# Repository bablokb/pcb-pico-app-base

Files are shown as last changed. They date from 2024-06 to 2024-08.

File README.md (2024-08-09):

Generic application base PCB for the Raspberry Pi Pico(W)
=========================================================

**This is work in progress**

A generic application base PCB for the Pi Pico(W) and compatible
development boards.

Core features:

  - RTC (PCF8563)
  - integrated power-management with
    - near zero power-off current
    - time-based wake up via RTC-alarm
    - wake up via interrupt (e.g. with a button)
    - JST-PH2 LiPo connector
    - LiPo charging
    - battery fuel-gauge
  - I2C connectors (Stemma/Qt and Grove)
  - EYESPI connector
  - integrated XTSD-chip for data-storage
  - additional THT for all GPIOs
  - multiple 3V3+GND connectors

License
-------

[![CC BY-SA 4.0][cc-by-sa-shield]][cc-by-sa]

This work is licensed under a
[Creative Commons Attribution-ShareAlike 4.0 International
License][cc-by-sa].

[][cc-by-sa]

[cc-by-sa]: http://creativecommons.org/licenses/by-sa/4.0/
[cc-by-sa-image]: https://licensebuttons.net/l/by-sa/4.0/88x31.png
[cc-by-sa-shield]:
https://img.shields.io/badge/License-CC%20BY--SA%204.0-lightgrey.svg

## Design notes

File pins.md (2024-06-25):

Pins
====

Pins on Raspberry Pi Pico
-------------------------

| | Pin  | Pin  | |
|---|---|---|---|
| | GP0  | VBUS |
| | GP1  | VSYS |
| | GND  | GND  |
| I2C1-SDA (RTC) | GP2  | EN |
| I2C1-SCL (RTC) | GP3  | 3V3  |
| DONE (Flip-Flop) | GP4  | VREF |
| | GP5  | GP28 | 
| | GND  | GND  |
| | GP6  | GP27 |
| | GP7  | GP26 | Display Busy (EYESPI)
| | GP8  | RUN  | RUN
| LCD-BL (EYESPI) | GP9  | GP22 | SD-CS (SD-Card)
| | GND  | GND  |
| | GP10 | GP21 | Display Reset (EYESPI)
| MEM-CS (EYESPI) | GP11 | GP20 | Display D/C (EYESPI)
| GPIO1 (EYESPI) | GP12 | GP19 | MOSI0 (EYESPI, SD-Card)
| GPIO2 (EYESPI) | GP13 | GP18 | SCLK0 (EYESPI, SD-Card)
| | GND  | GND  |
| TS-CS (EYESPI) | GP14 | GP17 | Display CS (EYESPI)
| INT (EYESPI) | GP15 | GP16 | MISO0 (EYESPI, SD-Card)

Pins on EYESPI
--------------

| Pin | Func | Mapped to
|-----|---|---|
| 1 | GPIO2 | GP13
| 2 | GPIO1 | GP12
| 3 | BUSY | GP26
| 4 | INT | GP15
| 5 | SDA | GP2
| 6 | SCL | GP3
| 7 | TS_CS | GP14
| 8 | MEM_CS  | GP11
| 9 | SD_CS | n.c.
|  10 | DISP_CS | GP17
|  11 | RESET | GP21
|  12 | DC | GP20
|  13 | MISO | GP16
|  14 | MOSI | GP19
|  15 | SCK | GP18
|  16 | GND | GND
|  17 | BLITE | GP9
|  18 | VCC | 3V3

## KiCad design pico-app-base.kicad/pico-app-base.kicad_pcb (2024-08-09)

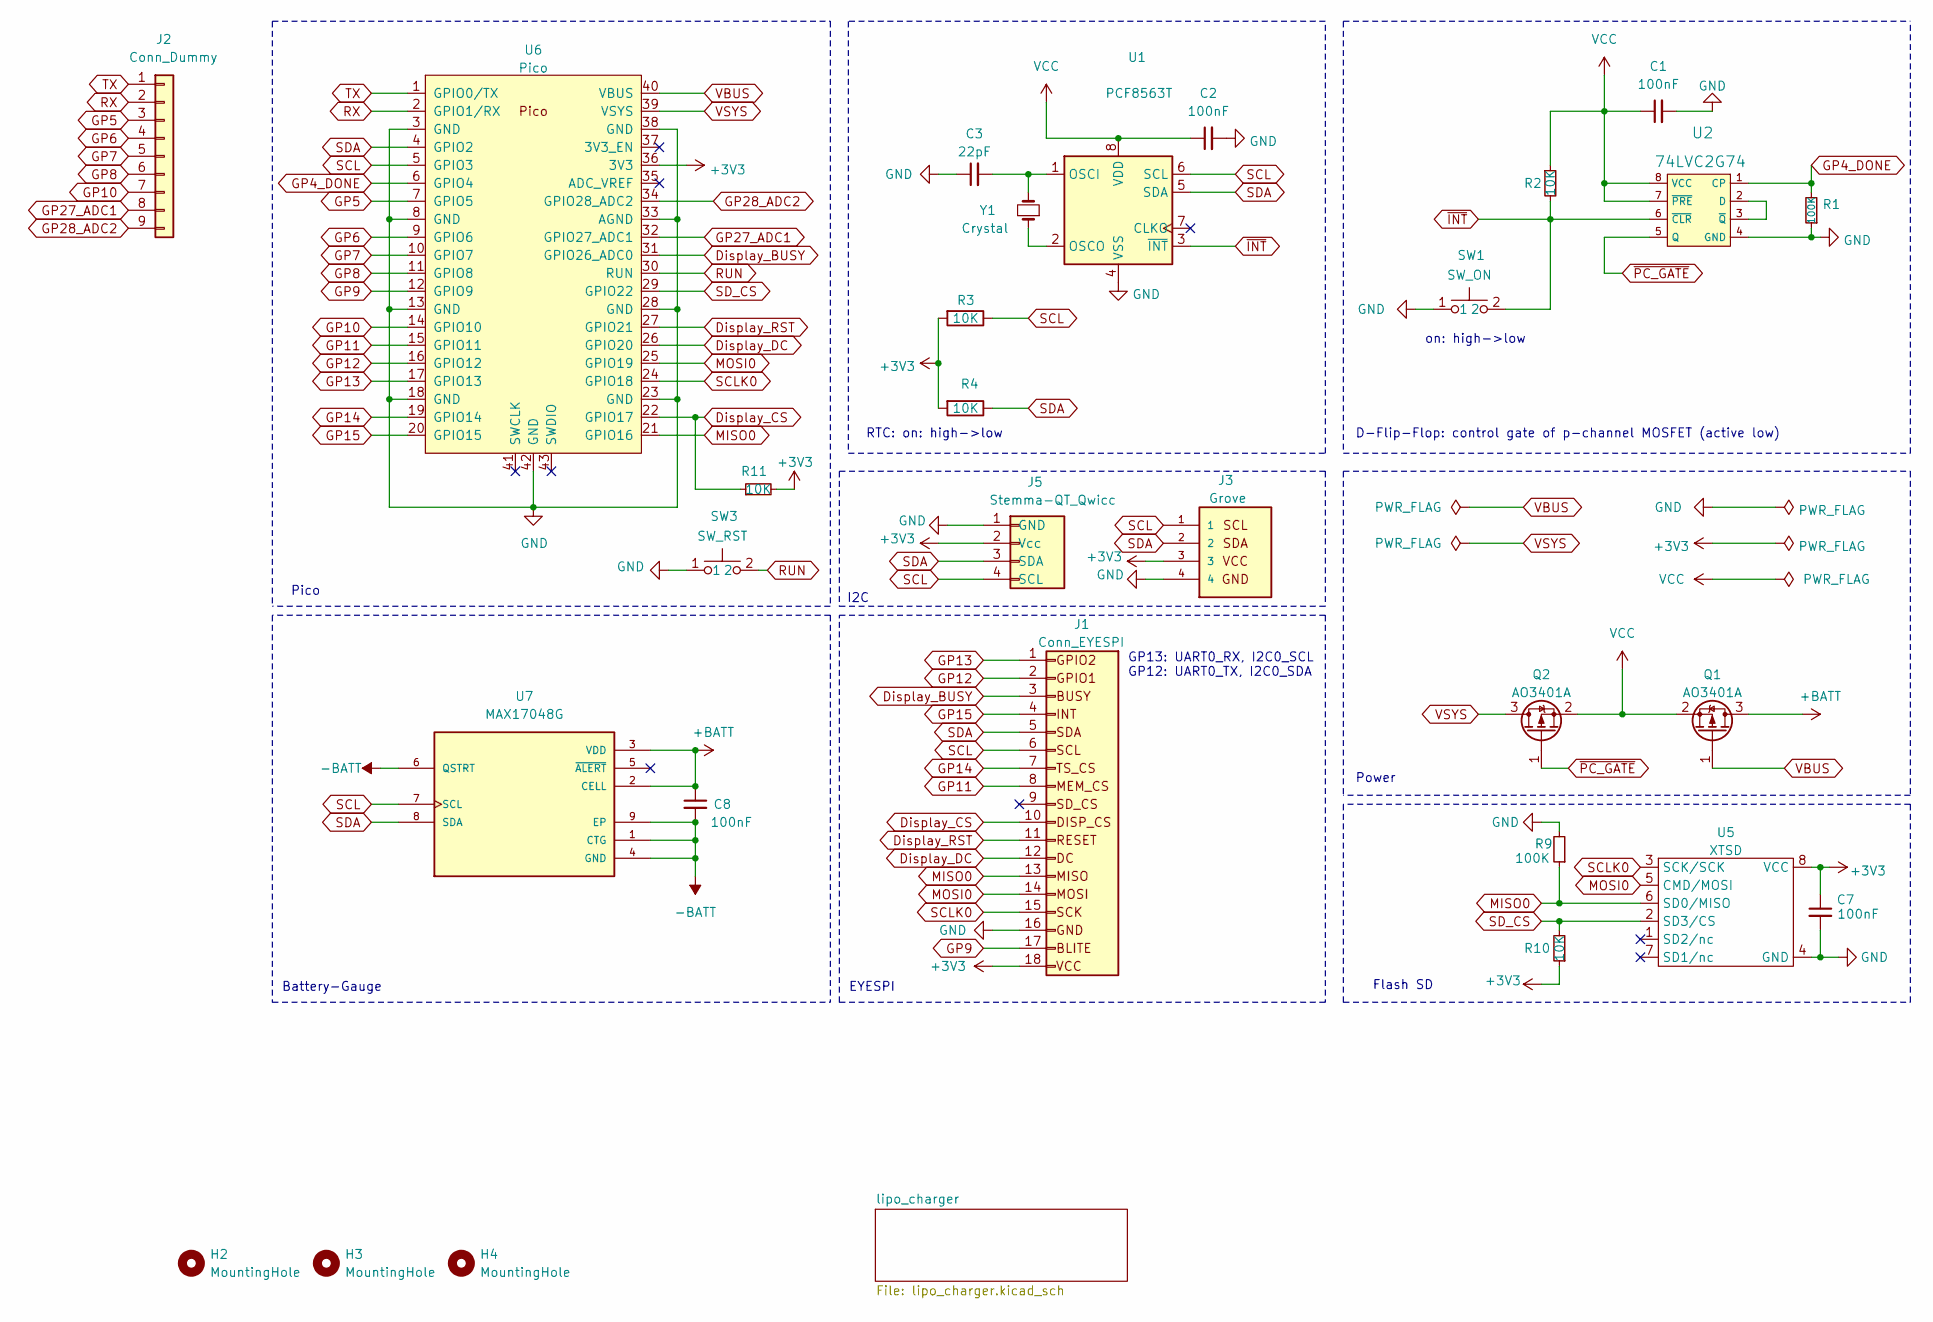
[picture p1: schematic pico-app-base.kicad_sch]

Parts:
C1, C2, C7, C8: 100nF; C_0402_1005Metric; LCSC C1525
C3: 22pF; C_0402_1005Metric; LCSC C1555
H2, H3, H4: MountingHole; MountingHole_2.5mm
J1: Conn_EYESPI; G-Shell-FPC_1x18_P0.50mm_Horizontal; LCSC C21260844
J2: Conn_Dummy
J3: Grove; grove_vertical
J5: Stemma-QT_Qwicc; JST_SH_SM04B-SRSS-TB_1x04-1MP_P1.00mm_Horizontal; LCSC C160404
Q1, Q2: AO3401A; SOT-23; LCSC C15127
R1, R9: 100K; R_0402_1005Metric; LCSC C25741
R2, R3, R4, R10, R11: 10K; R_0402_1005Metric; LCSC C25744
SW1: SW_ON; SW_PUSH_1x_6mm
SW3: SW_RST; SW_PUSH_1x_6mm
U1: PCF8563T; SOIC-8_3.9x4.9mm_P1.27mm; LCSC C7440
U2: 74LVC2G74; TSSOP-8_3x3mm_P0.65mm; MPN SN74HC74N; Digi-Key_PN 296-1602-5-ND
U5: XTSD; LGA8_8X6; LCSC C558837
U6: Pico; RPi_Pico_SMD_TH_extended
U7: MAX17048G; LCSC C2682616
Y1: Crystal; Crystal_SMD_3215-2Pin_3.2x1.5mm; LCSC C32346

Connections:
+3V3: C7.1, J1.18, J3.3, J5.2 (Vcc), R3.2, R4.2, R10.1, R11.2, U5.8 (VCC), U6.36 (3V3)
+BATT: C8.1, Q1.3 (D), U7.2 (CELL), U7.3 (VDD); also elsewhere on the board
-BATT: C8.2, U7.1 (CTG), U7.4 (GND), U7.6 (QSTRT), U7.9 (EP); also elsewhere on the board
Display_BUSY: J1.3, U6.31 (GPIO26_ADC0)
Display_CS: J1.10, R11.1, U6.22 (GPIO17)
Display_DC: J1.12, U6.26 (GPIO20)
Display_RST: J1.11, U6.27 (GPIO21)
GND: C1.2, C2.2, C3.1, C7.2, J1.16, J3.4, J5.1 (GND), R1.1, R9.2, SW1.1, SW3.1, U1.4 (VSS), U2.4 (GND), U5.4 (GND), U6.3 (GND), U6.8 (GND), U6.13 (GND), U6.18 (GND), U6.23 (GND), U6.28 (GND), U6.33 (AGND), U6.38 (GND), U6.42 (GND); also elsewhere on the board
GP4_DONE: R1.2, U2.1 (CP), U6.6 (GPIO4)
GP5: J2.3, U6.7 (GPIO5)
GP6: J2.4, U6.9 (GPIO6)
GP7: J2.5, U6.10 (GPIO7)
GP8: J2.6, U6.11 (GPIO8)
GP9: J1.17, U6.12 (GPIO9)
GP10: J2.7, U6.14 (GPIO10)
GP11: J1.8, U6.15 (GPIO11)
GP12: J1.2, U6.16 (GPIO12)
GP13: J1.1, U6.17 (GPIO13)
GP14: J1.7, U6.19 (GPIO14)
GP15: J1.4, U6.20 (GPIO15)
GP27_ADC1: J2.8, U6.32 (GPIO27_ADC1)
GP28_ADC2: J2.9, U6.34 (GPIO28_ADC2)
MISO0: J1.13, R9.1, U5.6 (SD0/MISO), U6.21 (GPIO16)
MOSI0: J1.14, U5.5 (CMD/MOSI), U6.25 (GPIO19)
unnamed: C3.2, U1.1 (OSCI), Y1.2
unnamed: U1.2 (OSCO), Y1.1
unnamed: U2.2 (D), U2.3 (~Q)
RUN: SW3.2, U6.30 (RUN)
RX: J2.2, U6.2 (GPIO1/RX)
SCL: J1.6, J3.1, J5.4 (SCL), R3.1, U1.6 (SCL), U6.5 (GPIO3), U7.7 (SCL)
SCLK0: J1.15, U5.3 (SCK/SCK), U6.24 (GPIO18)
SDA: J1.5, J3.2, J5.3 (SDA), R4.1, U1.5 (SDA), U6.4 (GPIO2), U7.8 (SDA)
SD_CS: R10.2, U5.2 (SD3/CS), U6.29 (GPIO22)
TX: J2.1, U6.1 (GPIO0/TX)
VBUS: Q1.1 (G), U6.40 (VBUS); also elsewhere on the board
VCC: C1.1, C2.1, Q1.2 (S), Q2.2 (S), R2.1, U1.8 (VDD), U2.7 (~PRE), U2.8 (VCC)
VSYS: Q2.3 (D), U6.39 (VSYS)
~INT: R2.2, SW1.2, U1.3 (~INT), U2.6 (~CLR)
~PC_GATE: Q2.1 (G), U2.5 (Q)

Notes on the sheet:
Battery-Gauge
EYESPI
Power
Flash SD
D-Flip-Flop: control gate of p-channel MOSFET (active low)
Pico
RTC: on: high->low
I2C
on: high->low
GP13: UART0_RX, I2C0_SCL GP12: UART0_TX, I2C0_SDA

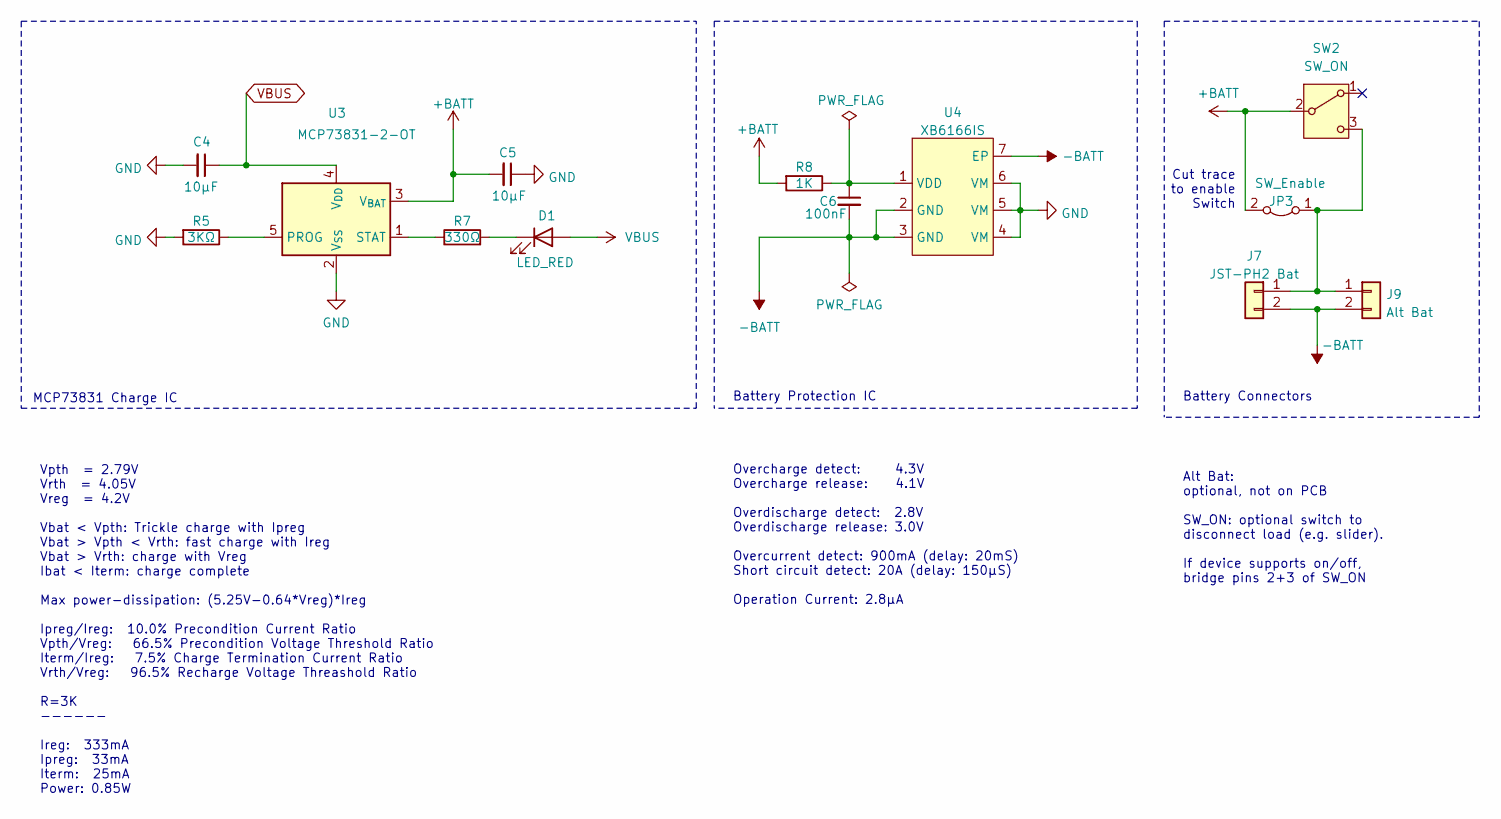
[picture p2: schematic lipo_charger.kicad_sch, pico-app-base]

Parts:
C4, C5: 10µF; C_0603_1608Metric; LCSC C19702
C6: 100nF; C_0402_1005Metric; LCSC C1525
D1: LED_RED; LED_0805_2012Metric; LCSC C84256
J7: JST-PH2 Bat; JST_PH_S2B-PH-SM4-TB_1x02-1MP_P2.00mm_Horizontal; LCSC C295747
J9: Alt Bat; PinHeader_1x02_P2.54mm_Vertical
JP3: SW_Enable; SolderJumper-2_P1.3mm_Bridged_Pad1.0x1.5mm
R5: 3KΩ; R_0603_1608Metric; LCSC C4211
R7: 330Ω; R_0402_1005Metric; LCSC C25104
R8: 1K; R_0603_1608Metric; LCSC C21190
SW2: SW_ON; PinHeader_1x03_P2.54mm_Vertical
U3: MCP73831-2-OT; SOT-23-5; LCSC C424093
U4: XB6166IS; DFN-2x2mm-0.75; LCSC C94310

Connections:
+BATT: C5.2, JP3.2 (B), R8.2, SW2.2 (B), U3.3 (V_{BAT}); also elsewhere on the board
-BATT: C6.2, J7.2, J9.2, U4.2 (GND), U4.3 (GND), U4.7 (EP); also elsewhere on the board
GND: C4.2, C5.1, R5.2, U3.2 (V_{SS}), U4.4 (VM), U4.5 (VM), U4.6 (VM); also elsewhere on the board
unnamed: D1.1 (K), R7.2
unnamed: J7.1, J9.1, JP3.1 (A), SW2.3 (C)
unnamed: R5.1, U3.5 (PROG)
unnamed: R7.1, U3.1 (STAT)
unnamed: C6.1, R8.1, U4.1 (VDD)
VBUS: C4.1, D1.2 (A), U3.4 (V_{DD}); also elsewhere on the board

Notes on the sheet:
Alt Bat: optional, not on PCB SW_ON: optional switch to disconnect load (e.g. slider). If device supports on/off, bridge pins 2+3 of SW_ON
Battery Connectors
MCP73831 Charge IC
Vpth = 2.79V Vrth = 4.05V Vreg = 4.2V Vbat < Vpth: Trickle charge with Ipreg Vbat > Vpth < Vrth: fast charge with Ireg Vbat > Vrth: charge with Vreg Ibat < Iterm: charge complete Max power-dissipation: (5.25V-0.64*Vreg)*Ireg Ipreg/Ireg: 10.0% Precondition Current Ratio Vpth/Vreg: 66.5% Precondition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
Battery Protection IC
Overcharge detect: 4.3V Overcharge release: 4.1V Overdischarge detect: 2.8V Overdischarge release: 3.0V Overcurrent detect: 900mA (delay: 20mS) Short circuit detect: 20A (delay: 150µS) Operation Current: 2.8µA
Cut trace to enable Switch

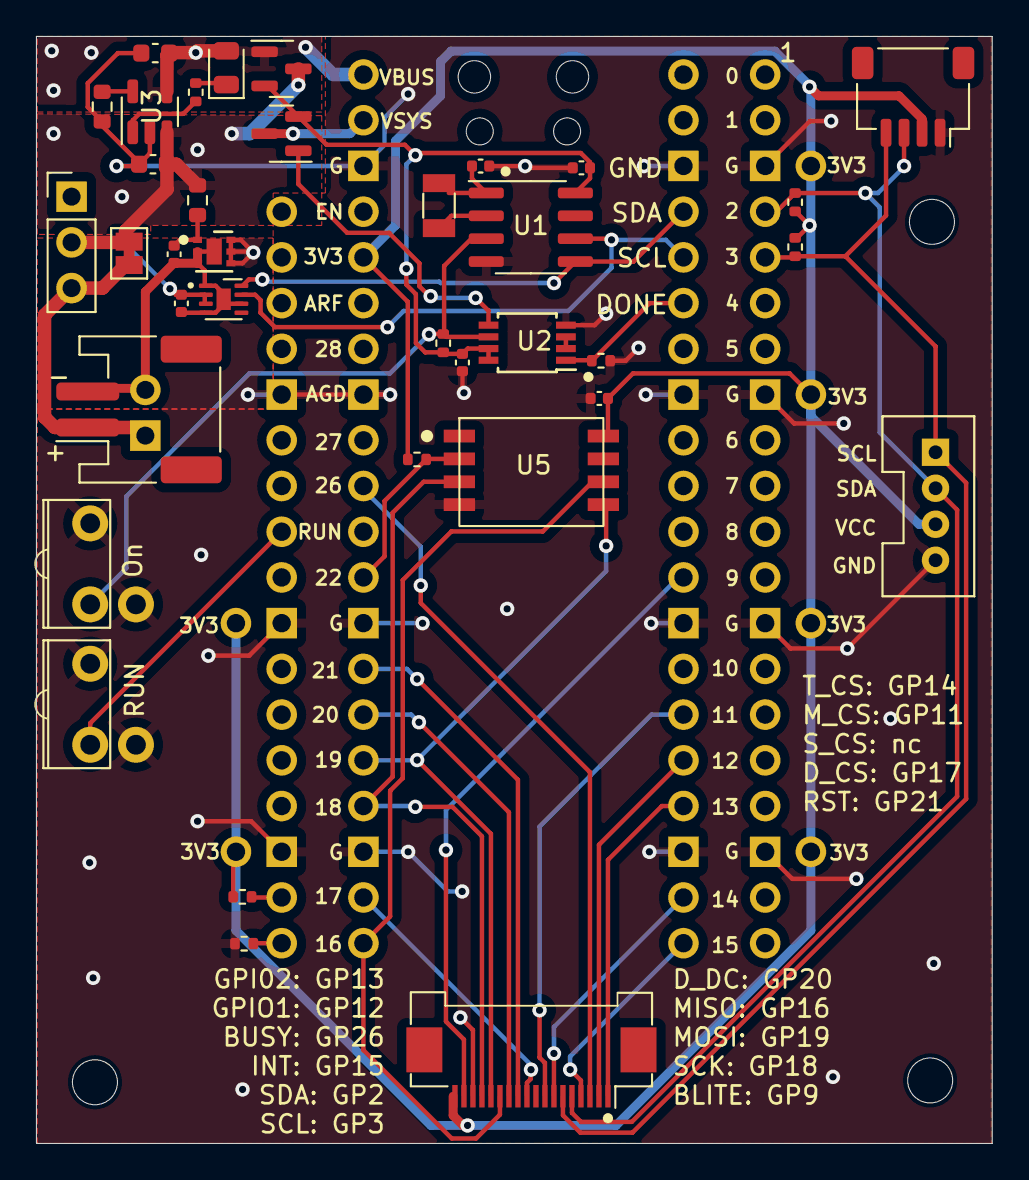
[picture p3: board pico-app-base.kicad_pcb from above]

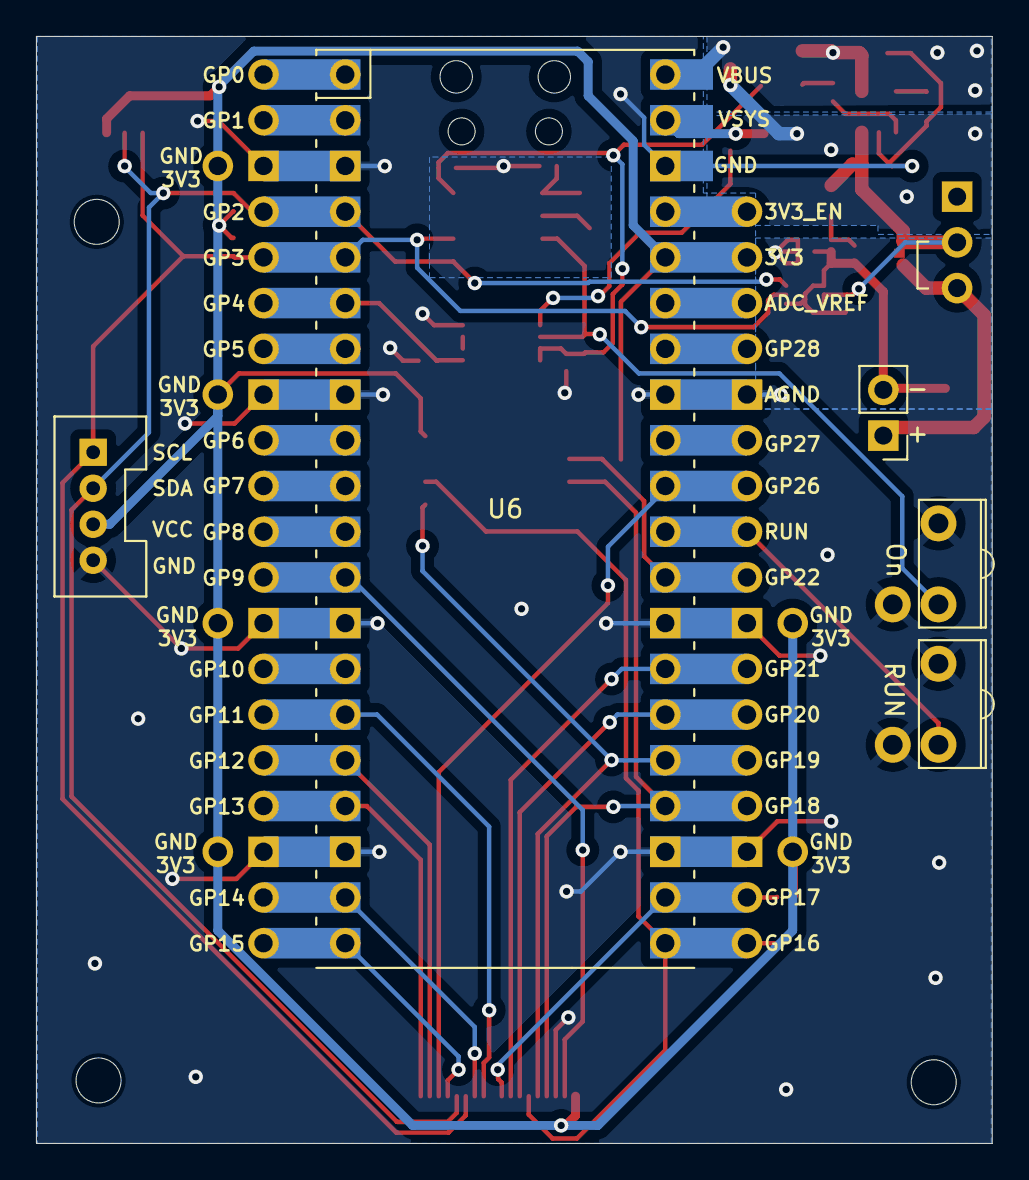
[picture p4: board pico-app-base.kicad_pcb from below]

Board: 2 copper layers, 53.1 x 61.5 mm, 41 parts (2 on the bottom side), 35 nets.

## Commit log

2024-05-16 preliminary version
    [lipo_charger.kicad_sch, pico-app-base.kicad_pcb, pico-app-base.kicad_sch]
2024-05-28 added zones and connections
    [lipo_charger.kicad_sch, pico-app-base.kicad_pcb, pico-app-base.kicad_sch]
2024-06-10 switched order of mosfets
    [lipo_charger.kicad_sch, pico-app-base.kicad_pcb, pico-app-base.kicad_sch]
2024-06-20 added I2C-grove, completed routing
    [lipo_charger.kicad_sch, pico-app-base.kicad_pcb, pico-app-base.kicad_sch]
2024-06-25 document pin usage
2024-06-25 added labels
    [pico-app-base.kicad_pcb]
2024-08-09 added battery-fuel gauge
    [lipo_charger.kicad_sch, pico-app-base.kicad_pcb, pico-app-base.kicad_sch]
